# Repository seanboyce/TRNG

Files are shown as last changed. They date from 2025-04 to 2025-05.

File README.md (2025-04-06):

# Function

This circuit is designed to output random bytes out MQTT, each as a message. It works at 8-10k bytes per second depending on system voltage and the fact that the bitrate of the entropy source is variable by nature.

# What? Why? You could just use a seed phrase and standard cryptography

Yeah, that works fine and there's no real disadvantage.

I've been designing various quantum TRNGs for nearly 15 years as part of an elaborate practical joke. This is just the latest one. I won't tell you what the joke is. Perhaps I'll never tell anyone. 

The world could do with a little more whimsy and playful mystery right now, and this is just my little bit that I can share with you.

# How it works

The core entropy source is two transistors in an unusual configuration. This is an old technique analogous to the classic "zener diode" method. It has the advantage of producing a slower signal, easier to sample.
It outputs avalanche noise with heavy DC bias. There's some nice [summary here](http://www.reallyreallyrandom.com/zener/why-its-random/index.html).

We remove the DC component wth a capacitor, then use two hex inverters for amplification and pulse-shaping. The first hex inverter is running at ~12V and is configured as two inverting amplifiers -- this is really power inefficient and it gets a bit warm due to the digital part working in linear modes. A little heat sink is recommended. 

This unusual use of the hex inverter is to reduce the parts count and cost -- I have a lot of hex inverters lying around. If you needed better power efficiency (e.g. for battery-powered use), you could use an op-amp. OPA132 is pretty easy to use.

The next hex inverter operates more or less digitally, just shaping the signal into a clean square wave. This one does not get warm.

After that, an Attiny261A acts as a Von Neumann extractor to convert the square wave into usable, unbiased bits of entropy. 

The bytes are read by a Pi Pico W and pushed out MQTT. Basic authentication works. I didn't bother adding TLS.

It would be possible to just use the PIO of the Pi Pico instead of an Attiny261A. However, most of the time I don't actually want the Pi Pico or Wi-Fi, and am just using the entropy locally. If you wanted to do this, you would simply not populate the Attiny261A, and solder a wire between pin 9 of the Attiny socket, and whatever pin you want on the Pi Pico. That will bypass the Attiny261A and push the raw entropy signal directly to the Pi Pico. I would recommend writing your own Von Neumann extractor with the PIO.

# How to build it

## Notes on surface mount components

This design makes extensive use of surface-mount components. I have limited budget and time to spend on my hobbies, so I generally use the smallest possible SMT components to save both (standardize my parts library). If you find 0402 difficult to work with, then it's very fast to open up the KiCAD files in this repo, and replace all the 0402 resistors with 0603 in the schematic. Then just pull up the board design, update from the schematic, and touch up the routing -- you should be good to go, 0603 is pretty easy to hand-solder even without a hot air rework station and solder paste. A normal iron, coil of solder, and some patience will suffice.

If you want to redesign everything as through-hole, this will require a bit of a redesign. I would recommend purchasing a USB boost converter, not populating the integrated boost converter, and using the passthrough I've left you (J2). Then switch the CD4069 to the DIP version, and add in through-hole resistors and capacitors. I vaguely recall that the DIP version of the CD4069 has better thermal dissipation, you might be able to get away with a smaller heat sink or none at all -- I've gotten away without one in older designs (give it a careful test though).

## Building the current design

I recommend building the boost converter first, then give it some power and make sure the output voltage is sane. Should be between 12 and 13 volts. Note that the EN pin of the MT3608 should be connected to Vin -- else nothing will output at all. I just bridge the middle pin of J1 to Vin.

Once that's in, I put in the transistors (mind polarity!), the first hex inverter, and all the resistors and capacitors around them. Then I supply power again, for a short time, with a scope connected to the output of the first hex inverter. The scope is set to be AC coupled. I should see a pretty looking signal with a lot of noise. Then I cut power -- that first hex inverter can get sort of hot with no heat sink attached.

Then I get the buck converter / LM7803 in, as well as the final hex inverter. Then I test as above (scope can be AC or DC coupled), making sure the signal from the second hex inverter is a weird looking, but mostly clean square wave ranging from 0 to 3.3V.

If that's good, I flash the program (main.asm) to an Attiny261A (using AVR-ICE, STK500 or home-made programmer). For the first few boards, I put in a socket for the AVR, so I can pull it out and update the firmware. Then I quickly check again, specifically that the "new output" pin of the Attiny261A is pushing out 10 usec pusles, and that bits are coming out of the pins of PORTA.

At this point, I just load the program (main.py) into the Pi Pico, disconnect it from the USB cable, and plug it in. The onboard LED should light up if it's receiving power, and flicker slightly if it's pushing out MQTT. If it doesn't flicker, try turning it off and on again, sometimes it can fail to connect to Wi-Fi.

**DO NOT plug a USB cable into the Pi Pico while it is connected to this circuit** It is being powered by 3.3V. USB is 5V. Several components are likely to make sad electronic noises, fail violently, and lose their magic blue smoke.

As for what part goes where? It's all in the KiCAD schematic. I would recommend giving it a detailed look.

## The Von Neumann Extractor

This just measures two time intervals between 2 sets of 2 independent events (it could probably use 3 events instead of 4 to calculate 2 intervals, but whatever. It's much faster than fast enough now). If t1>t2, it records a 0. If t1<t2, it records a 1. If they are equal, it tries again.

I originally wrote this firmware *ages* ago. It was quite an experience to look at my ham-fisted assembly from 15 years ago. I redid it with many optimizations, which increased performance about 50x. Also it consumes less power. Use main.asm, not old_von_neumann.asm. Seriously, the latter is pretty awful.

I include both files, so that one day I may look back and consider *both attempts* primitive and silly. Got to keep that ego in check!

## Photo

Note the black "bodge wire" near the USB power input. This was necessary because of an error in the original design files. The version in this repository has been corrected, and you won't need to cut any traces / add weird wires and so on.

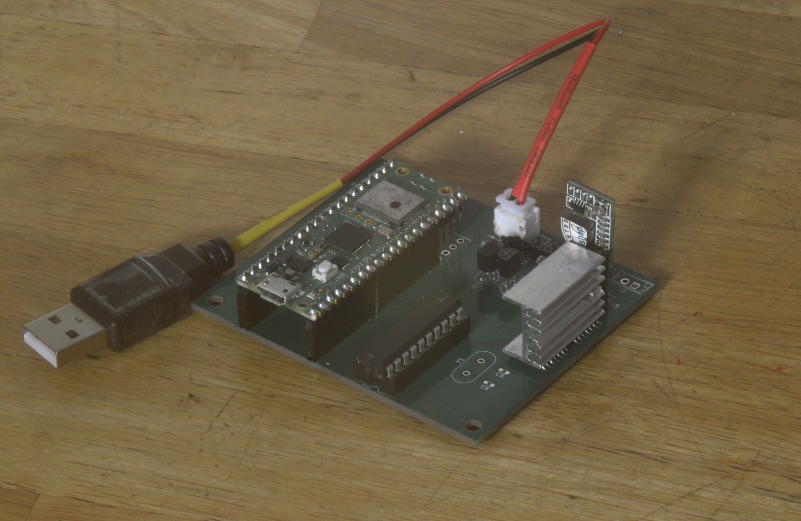
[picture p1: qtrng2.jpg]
photo of the trng


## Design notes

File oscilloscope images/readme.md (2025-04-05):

# Oscilloscope traces

These are here to help with any troubleshooting. There's some noise, mainly cause by he trying to hold 4 things in place at once rather than connect things to the board properly.

The first image is of the raw avalanche signal, AC coupled, just past C1. It has a strong DC bias before C1.

The second image is the cleaned signal coming out of the final hex inverter stage.

The final image is the 10usec pulse that come out of the attiny261A every time a new byte is ready.

If your signals don't look mostly like these, it's not working properly, even if you're getting output!

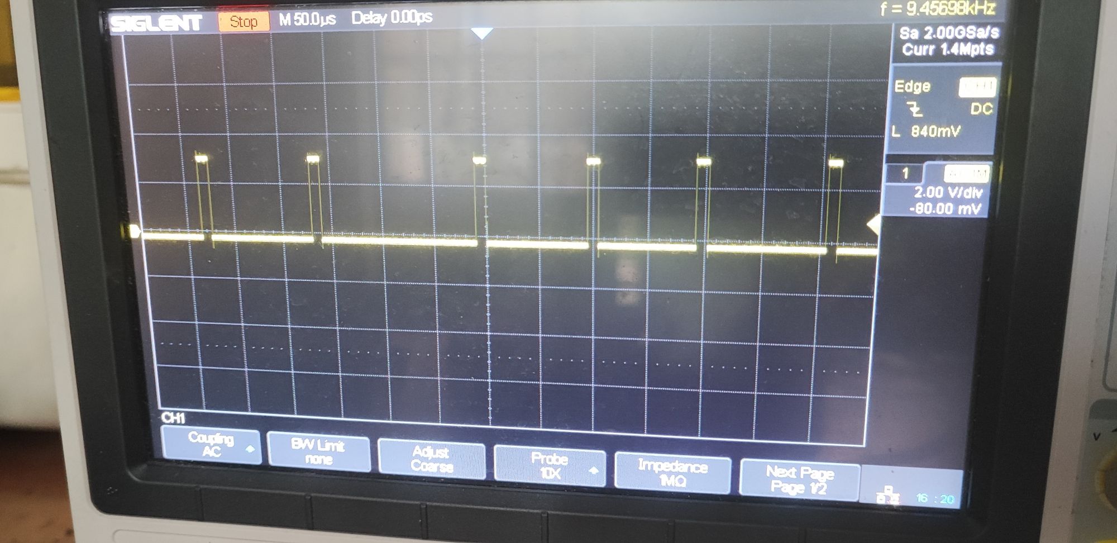
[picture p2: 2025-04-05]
oscilloscope images/3_new_data_pin.jpg

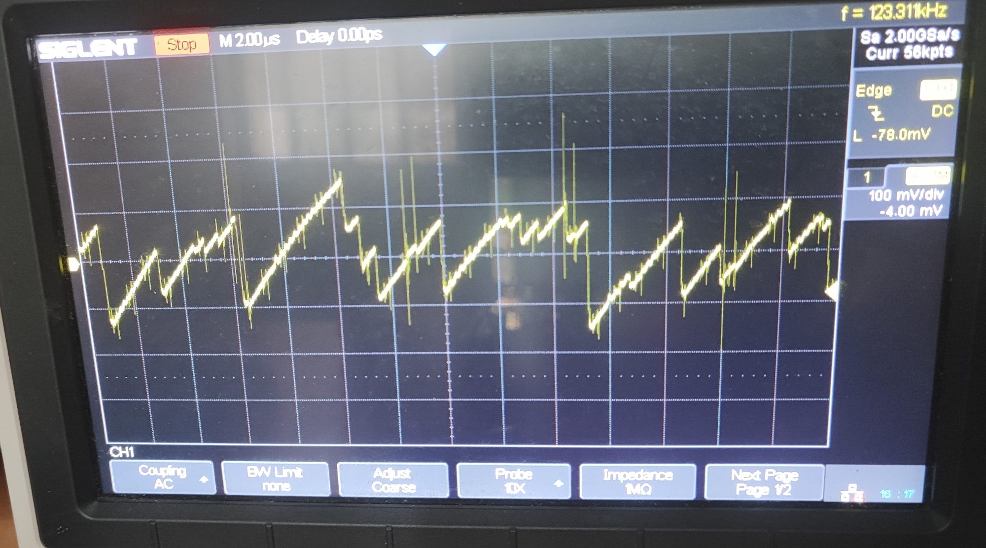
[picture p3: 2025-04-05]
oscilloscope images/1_transistor_output.jpg

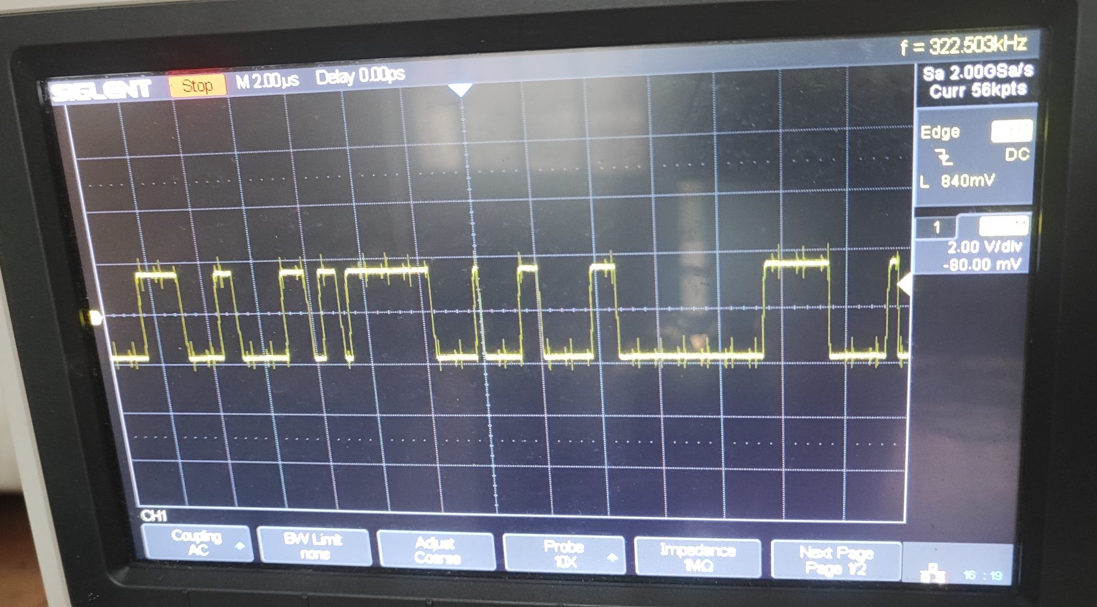
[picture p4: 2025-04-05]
oscilloscope images/2_final_hex_inverter_output.jpg

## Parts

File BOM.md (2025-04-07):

# Required:

## Resistors (all 0402):
- 1x 20k
- 1x 1k
- 3x 50k
- 1x 1M

## Capacitors and Inductors:
- 2x 22uF ceramic non-polar 1206
- 3x 0.1uF ceramic non-polar 0603
- 1x 22uH coil. Check size against KiCAD footprint.

## Discrete semiconductors:
- 1x SS24 Schottky diode SMT (unsure of package)
- 2x 2N5551 transistors TO-92

## ICs and modules:
- 2x CD4069UBM hex inverters
- 1x MT3608 boost converter IC
- 1x buck converter module -- the tiny cheap ones with just EN, Vin, GND, Vout
- 1x Attiny 261A
- 1x Pi Pico W

# Optional:
- 1x crystal
- 2x 12pF ceramic non-polar 0603
- 2x two-pin JST connector
- 1x LM7803 linear regulator (alternative to a buck converter to get 3.3V)
- ~~1x covenant with the Old Powers~~
- You'll probably want some female 2.5mm headers for the Pi Pico.

#Notes: 

1. The optional crystal as a clock source for the attiny is untested. Maybe double check I connected it right. If using it, the 12pF caps are required.
2. The JST connectors are handly for connecting power to the board through J1. It's expected that you bridge the middle pin of J1 to VCC of the input voltage. It's connected to the enable pin of the MT3608
3. J2 lets you bypass the integrated boost converter, e.g. if you just want to supply ~12V to the board. In this case, all of the boost converter parts should not be added to the board.
4. Strictly speaking, the Attiny261A could be eliminated by just using the PIO of the pi pico. However, I often use this design in cases where Internet connectivity is not useful -- in these cases I just don't populate the Pi Pico, which is more expensive than an Attiny261A.
5. Exact resistor values are not critical, however 1 + 0.6(R5/R6) gives you the output voltage of the boost converter. A ratio of 20 should get you between 12 and 13 volts.
6. Exact capacitor values are not critical either, except on the boost converter (those two 22uF)
7. Heck, the exact Schottky diode doesn't really matter much either. I just used the one I had
8. You can use other transistors, however 2N5551 starts avalanching at a relatively low voltage. Others may work. I selected the 2N5551 after trying a few types and measuring the avalanche signal frequency and the voltage it started at. It's probably not the best one, just the best one I have in stock.
9. Attiny261A is just the one I had lying around. I've also made this circuit with the attiny10 -- it just raises one of two outputs high when triggered, essentially providing one-shot, one bit output.

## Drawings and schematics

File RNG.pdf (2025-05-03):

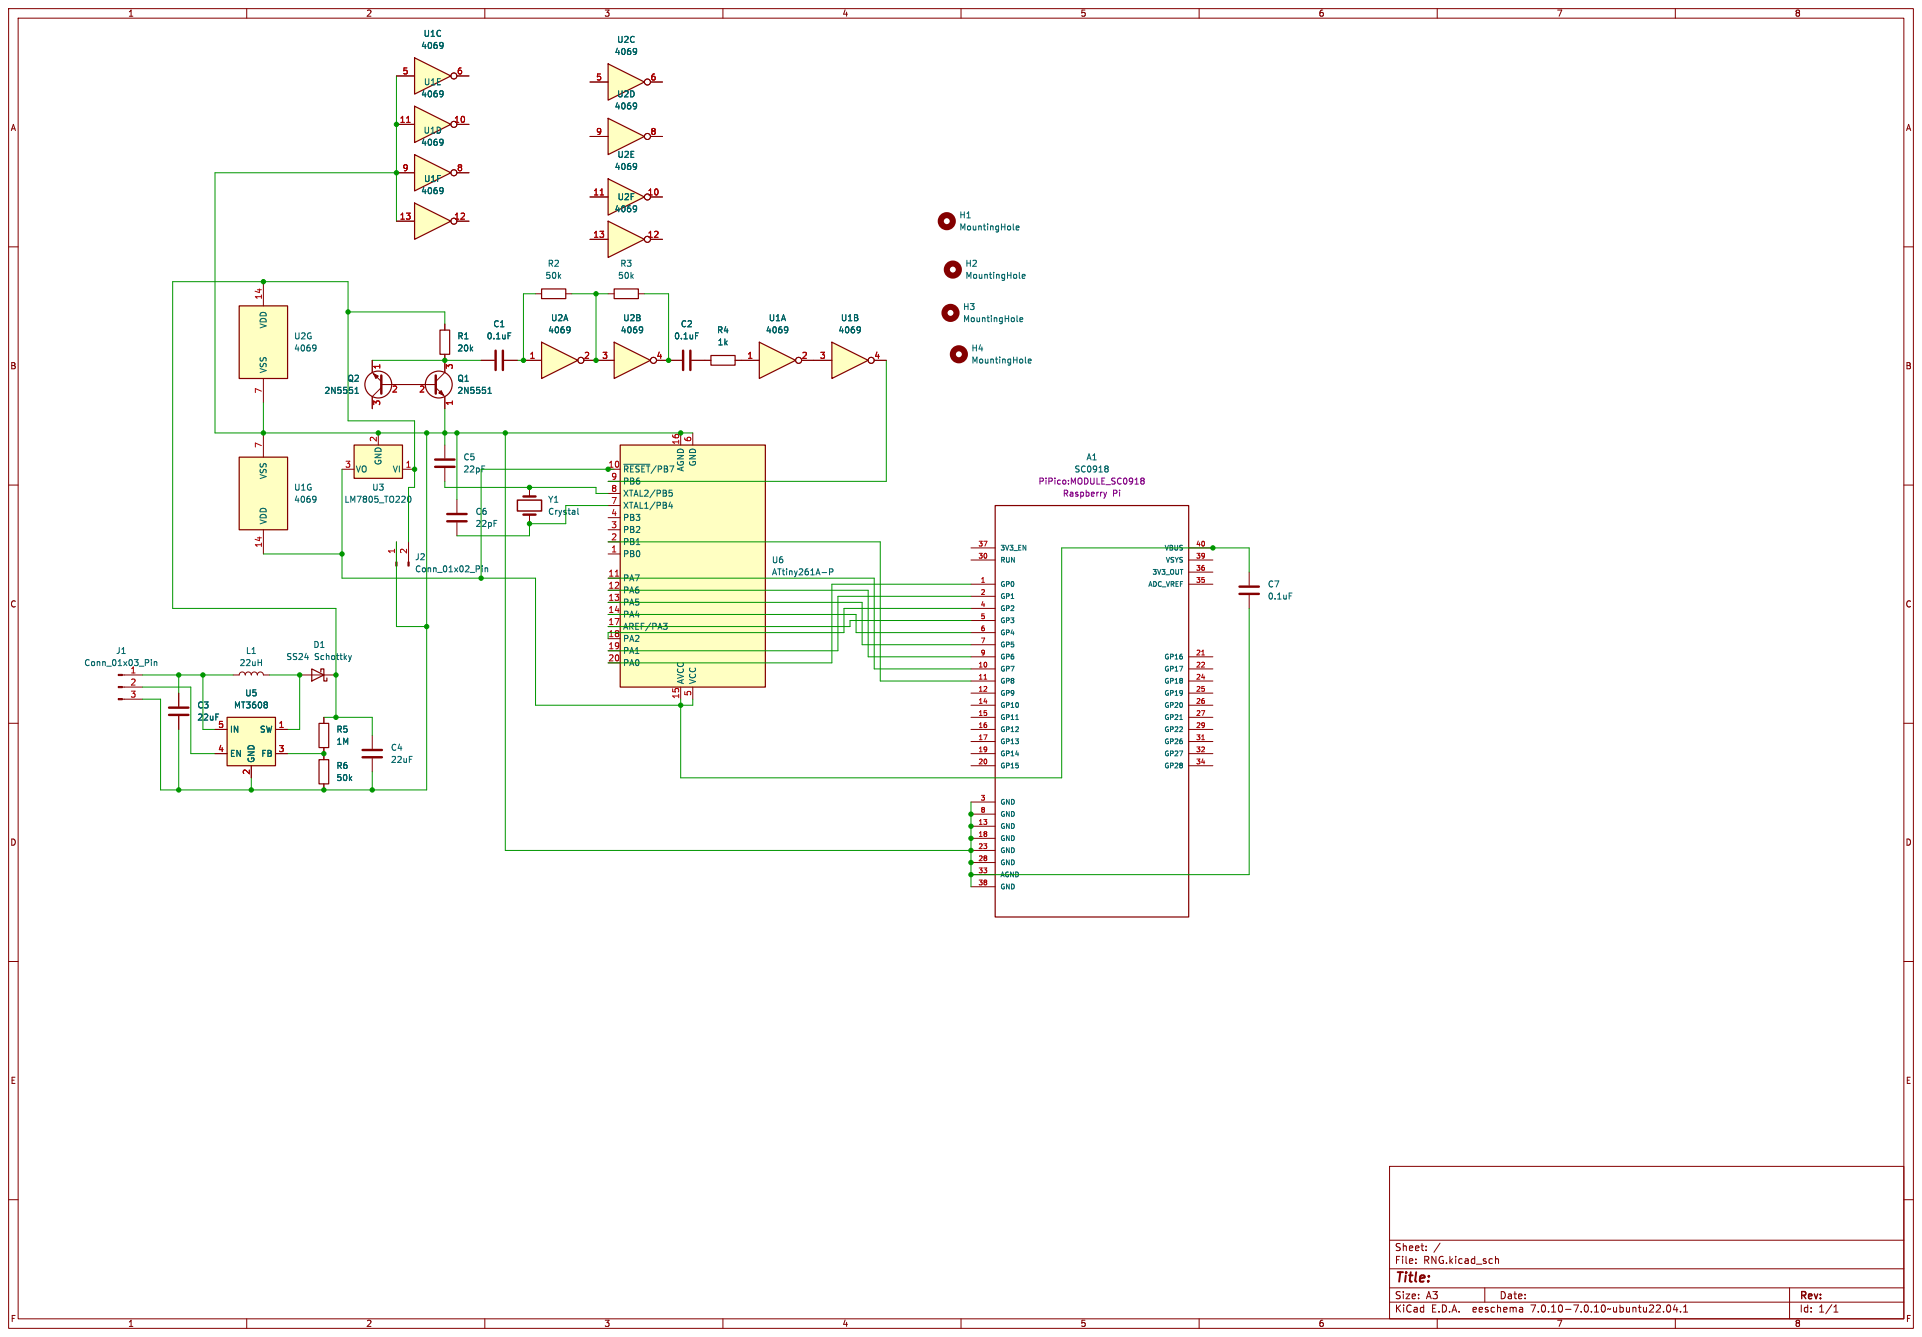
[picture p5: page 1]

H1 MountingHole H3 MountingHole H2 MountingHole H4 MountingHole

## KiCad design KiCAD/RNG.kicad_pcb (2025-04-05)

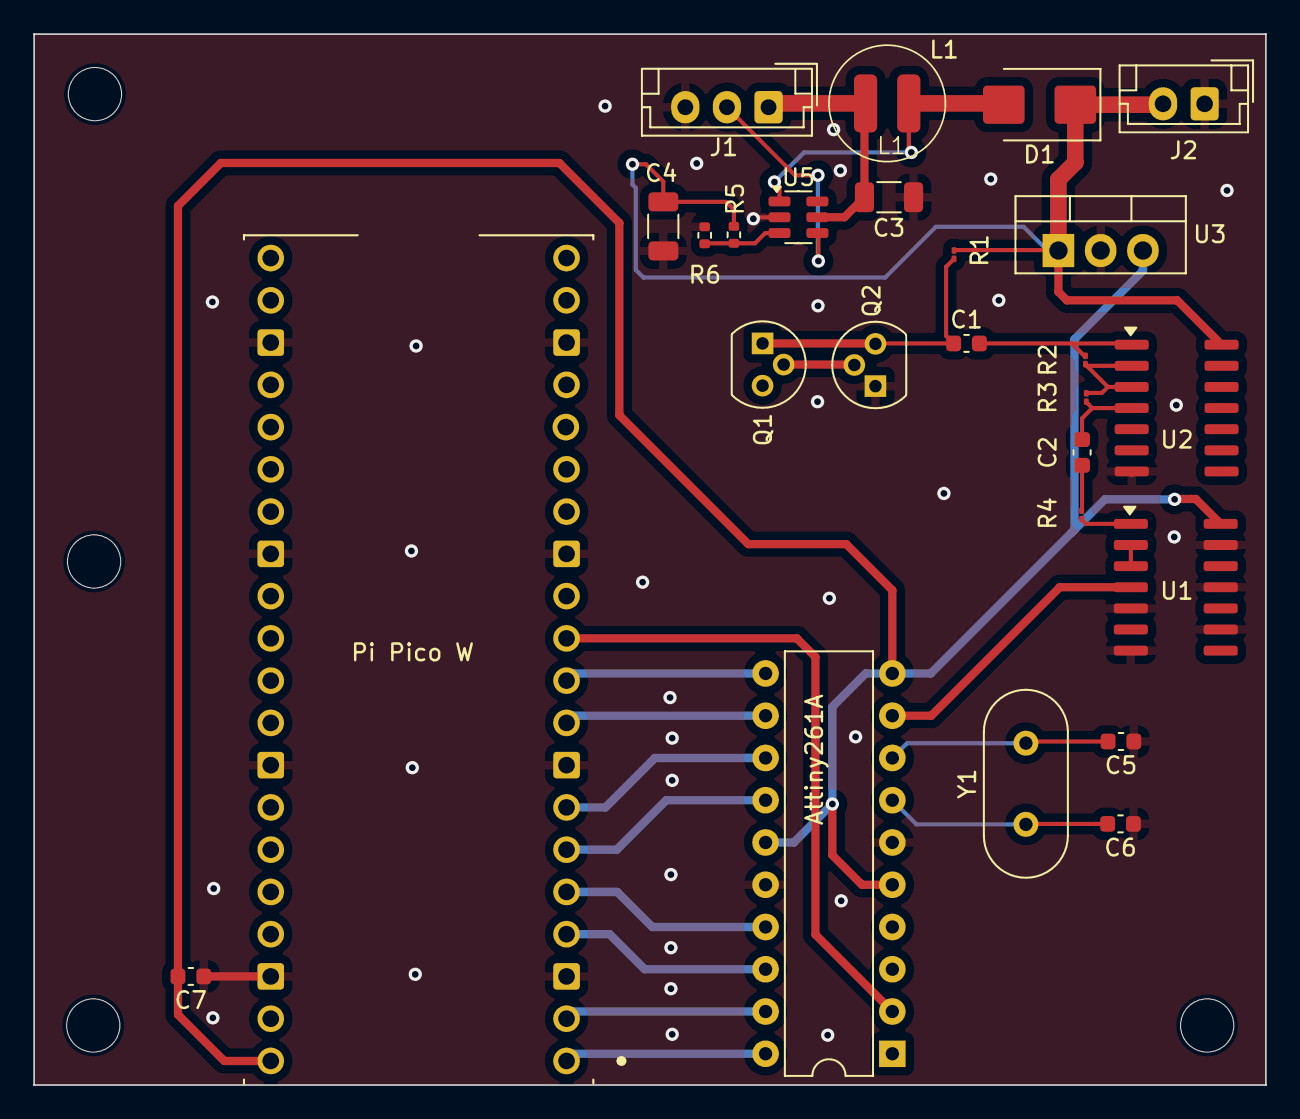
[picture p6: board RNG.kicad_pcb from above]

Board: 2 copper layers, 74.0 x 63.2 mm, 28 parts (0 on the bottom side), 24 nets.

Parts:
A1: SC0918; MODULE_SC0918
C1, C2, C7: 0.1uF; C_0603_1608Metric
C3, C4: C; C_1206_3216Metric
C5, C6: 22pF; C_0603_1608Metric
D1: D_Schottky; D_SMB
H1, H2, H3, H4: MountingHole; MountingHole_3.2mm_M3
J1: Conn_01x03_Pin; JST_EH_B3B-EH-A_1x03_P2.50mm_Vertical
J2: Conn_01x02_Pin; JST_EH_B2B-EH-A_1x02_P2.50mm_Vertical
L1: L; cd32
Q1, Q2: 2N5551; TO-92
R1: 20k; R_01005_0402Metric
R2, R3: 100k; R_01005_0402Metric
R4: 1k; R_01005_0402Metric
R5, R6: R; R_0402_1005Metric
U3: LM7805_TO220; TO-220-3_Vertical
U5: MT3608; SOT-23-6
U6: ATtiny261A-P; DIP-20_W7.62mm
Y1: Crystal; Crystal_HC49-U_Vertical

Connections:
unnamed: A1.3 (GND), A1.8 (GND), A1.13 (GND), A1.18 (GND), A1.23 (GND), A1.28 (GND), A1.33 (AGND), A1.38 (GND), C3.1, C4.2, C5.1, C6.1, C7.1, J1.3, J2.1, Q1.1 (E), R6.2, U3.2 (GND), U5.2 (GND), U6.6 (GND), U6.16 (AGND)
unnamed: A1.1 (GP0), U6.20 (PA0)
unnamed: A1.2 (GP1), U6.19 (PA1)
unnamed: A1.4 (GP2), U6.18 (PA2)
unnamed: A1.5 (GP3), U6.17 (AREF/PA3)
unnamed: A1.6 (GP4), U6.14 (PA4)
unnamed: A1.7 (GP5), U6.13 (PA5)
unnamed: A1.9 (GP6), U6.12 (PA6)
unnamed: A1.10 (GP7), U6.11 (PA7)
unnamed: A1.11 (GP8), U6.2 (PB1)
unnamed: A1.40 (VBUS), C7.2, U3.3 (VO), U6.5 (VCC), U6.10 (~RESET/PB7), U6.15 (AVCC)
unnamed: C1.2, R2.1
unnamed: C2.1, R3.2
unnamed: C2.2, R4.1
unnamed: D1.2 (A), L1.2, U5.1 (SW)
unnamed: C4.1, D1.1 (K), J2.2, R1.1, R5.1, U3.1 (VI)
unnamed: C3.2, J1.1, L1.1, U5.5 (IN)
unnamed: J1.2, U5.4 (EN)
unnamed: Q1.2 (B), Q2.2 (B)
unnamed: C1.1, Q1.3 (C), Q2.1 (E), R1.2
unnamed: R2.2, R3.1
unnamed: R5.2, R6.1, U5.3 (FB)
unnamed: C6.2, U6.7 (XTAL1/PB4), Y1.1
unnamed: C5.2, U6.8 (XTAL2/PB5), Y1.2

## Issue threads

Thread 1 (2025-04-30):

Add a PDF version of the design files

ospilos, 2025-04-30:
Mainly of the schematics. We are curious to see the exact circuit diagram, but not curious enough to install each and every EDA software besides the ones we use whenever we see a new interesting circuit.
Nevertheless, nice project and I hope for your crypto joke will stun and astound both your victim and audience.

seanboyce, 2025-05-03:
Sure, done! There's now a PDF of the schematic in the main directory for you.

As for the joke? I'm unlikely to ever reveal it. It's nice to have something secret to remember and laugh about sometimes :)

Oh, note that R1 should probably be more than 20k with the transistors in that configuration (as someone kindly pointed out). I stress tested for about a year and it was OK, but a higher value would be a bit less spicy. I'll get around to testing it and updating the schematics one of these weeks.

seanboyce, 2025-05-08:
Haha, no -- if those pranks exist, we don't mention them at all.

Closed 2025-05-03.

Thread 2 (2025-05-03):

R1 should probably be a higher resistance

seanboyce, 2025-05-03:
The transistors are being used in a very-not-recommended way (I *did* say the design was 'spicy'). Someone pointed out that the avalanche current will probably degrade them with time, and this could be somewhat mitigated by increasing the value of R1, probably to 100k or more. I'll test it before updating the schematics.

The current design was stress-tested for about a year, at which point I found no evidence of any problem. Still, I can't think of any good reason not to try and mitigate the issue -- it's not much work for me to just swap R1 with 100k or whatever and make sure the signal is still good. I'll find time to do so eventually, and then I'll close this issue.

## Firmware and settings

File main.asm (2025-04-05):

.include "tn261Adef.inc"
.CSEG
.ORG 0
rjmp RESET ; Reset Handler -- used for handling reset vector
rjmp event ; IRQ0 Handler -- used to detect falling edges for avalance events
rjmp RESET ; PCINT0 Handler -- not used
rjmp RESET ; Timer0 Capture Handler -- not used
rjmp RESET ; Timer0 Overflow Handler -- not used
rjmp RESET ; Timer0 Compare A Handler -- not used
rjmp RESET ; Timer0 Compare B Handler -- not used
rjmp RESET ; USI_OVF Handler -- not used
rjmp RESET ; EEPROM READY Handler -- not used
rjmp RESET ; Analog Comparator Handler -- not used
rjmp RESET ; ADC Conversion Complete Handler -- not used
rjmp RESET ; Watchdog Interrupt Handler -- not used
rjmp RESET ; INT1 -- not used
rjmp RESET ; TIMER0_COMPA -- not used
rjmp RESET ; TIMER0_COMPB -- not used
rjmp RESET ; TIMER0_CAPT -- not used
rjmp RESET ; TIMER1_COMPD -- not used
rjmp RESET ; FAULT_PROTECTION -- not used

RESET:
;BEGIN SETUP SECTION
CLR R16 ; cleanup
LDI r16, (1<<PRADC | 1<<PRTIM1 | 1<<PRUSI | 0<<PRTIM0); disable unused features to save power. We will use timer0.
OUT PRR, r16

ldi r16, (0<<CS02 | 0<<CS01) | (1<<CS00) ; set up timer, no prescaler
out TCCR0B, r16

ldi r16, (0<<ICEN0 | 0<<TCW0) | (0<<WGM00);Ensure normal 8-bit mode timer operation. Overflows are OK.
out TCCR0A, r16

;Set up ports. PortB, Pin 6 is input, pullup resistors disabled. The rest of A&B are used as potential outputs.
ldi r16,0b10111111 ; Set pin 6 as input, others as output
out DDRB,r16
ldi r16,0b00000000 ; make sure pullups are disabled, saves power. Also what's the point of reducing input noise when we're measuring noise?
out PORTB, r16
ldi r16,0b11111111 ; Port A as output
out DDRA,r16

LDI r16, (1<<ISC01 | 0<<ISC00 | 0<<SM0 | 0<<SM1 | 1<<SE); Interrupt on falling edge -- these are the avalanche events, we measure time between them. Set sleep mode IDLE and enable sleep.
;We could use deeper sleep, some state retention, and pin level interrupt instead of falling edge. This would save a little more power (irrelevant), at the cost of more complex code. We're not going to do that. 
OUT MCUCR, r16
LDI r16, (1<<INT0) ; actually enable INT0 (pin 9).
OUT GIMSK, r16
CLR R16 ; cleanup
CLR R21
; END SETUP SECTION


START:
; Set iteration number to 1
ldi r20, 0b00000001

CLR R21 ; clear out any stored entropy

;BEGIN SAMPLE 1 BIT
LOOP:
;WAIT for a first event to happen
SEI
SLEEP
;Now we start timing t1, the time between the first and second events.
out TCNT0L, r16 ; Clear timer
SEI ; enable global interrupt
SLEEP
MOV r17, r18 ; r17 is for the first bit
;Now we start timing t2, the time between the second and third events
out TCNT0L, r16 ; Clear timer
SEI ; enable global interrupt
SLEEP
NOP ; not really needed. Just for CPU cycle symmetry

cp r17, r18
breq LOOP ; if both timers equal, cancel this bit
cp r17, r18
brsh OUTPUT0 ; t1>t2, output 0
rjmp OUTPUT1 ; t1<t2, output 1

event:
IN r18,TCNT0L ; keep our interrupt routine tight
RET ;return but do not enable interrupts yet, we'll manage interrupts manually

OUTPUT0:
NOP ; Not needed. Just for symmetry.
cpi r20,0b10000000
brsh PAROUT
lsl r20 ; rotate iteration counter left -- just moves to the next bit.
RJMP LOOP

OUTPUT1:
add r21,r20
cpi r20,0b10000000
brsh PAROUT
lsl r20 ; rotate iteration counter left -- just moves to the next bit.
RJMP LOOP

PAROUT:
out PORTA,r21
out TCNT0L, r16 ; Clear timer
sbi PINB,1 ;toggle pin up
wait:
IN r18,TCNT0L ; just wait ~30usec. Not worth using sleep modes for this.
CPI r18, 0x50 ; wait 10usec
BRLT wait
sbi PINB,1 ;toggle pin down The reason we do this instead of just toggle once, is that the Pi Pico has no pin change interrupt. So on rising edge, it's always safe to read a value out of PORTA.
RJMP START

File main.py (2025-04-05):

from machine import Pin
import network
from time import sleep
from umqtt.simple import MQTTClient

# Setup LED, so we know it's on
led = machine.Pin("LED", machine.Pin.OUT)
led.toggle()

# Wi-Fi credentials
ssid = 'your_wifi_ssid'
password = 'your_wifi_password'

# A function to connect to Wi-Fi
def connect():
    #Connect to WLAN
    wlan = network.WLAN(network.STA_IF)
    wlan.active(True)
    wlan.connect(ssid, password)
    while wlan.isconnected() == False:
        print('Waiting for connection...')
        sleep(1)
    print(wlan.ifconfig())

# MQTT Server credentials
MQTT_SERVER = "your_mqtt_server"
MQTT_PORT = your_mqtt_port
MQTT_USER = "your_mqtt_username"
MQTT_PASSWORD = "your_mqtt_password"
MQTT_CLIENT_ID = ""
MQTT_KEEPALIVE = 7200
MQTT_SSL = False

#Initial states for data
data = 0
freshData = False

# A function to connect to MQTT
def connect_mqtt():
    try:
        client = MQTTClient(client_id=MQTT_CLIENT_ID,
                            server=MQTT_SERVER,
                            port=MQTT_PORT,
                            user=MQTT_USER,
                            password=MQTT_PASSWORD,
                            keepalive=MQTT_KEEPALIVE,
                            ssl=MQTT_SSL)
        client.connect()
        return client
    except Exception as e:
        print('Error connecting to MQTT:', e)
        raise  # Re-raise the exception to see the full traceback

# A function to publish to MQTT once connected
def publish_mqtt(topic, value):
    client.publish(topic, value)
    #print(topic)
    #print(value)
    #print("Publish Done")

# No Ports on raspberry pi, so we fake one with 8 pins
def readByte(newData):
    global data
    data = bit0.value() + 2*bit1.value() + 4* bit2.value() + 8*bit3.value() + 16*bit4.value() + 32*bit5.value() + 64*bit6.value() + 128*bit7.value()
    global freshData
    freshData = True


# Driver code on startup
connect()
client = connect_mqtt()

# Turn off LED once connected
led.toggle()


# Configure input pins
bit0 = Pin(0, Pin.IN, Pin.PULL_DOWN)
bit1 = Pin(1, Pin.IN, Pin.PULL_DOWN)
bit2 = Pin(2, Pin.IN, Pin.PULL_DOWN)
bit3 = Pin(3, Pin.IN, Pin.PULL_DOWN)
bit4 = Pin(4, Pin.IN, Pin.PULL_DOWN)
bit5 = Pin(5, Pin.IN, Pin.PULL_DOWN)
bit6 = Pin(6, Pin.IN, Pin.PULL_DOWN)
bit7 = Pin(7, Pin.IN, Pin.PULL_DOWN)
newData = Pin(8, mode=Pin.IN, pull=Pin.PULL_DOWN)
newData.irq(trigger=Pin.IRQ_RISING,handler=readByte)

print("Starting")

# Main loop. Basically fire off a byte out MQTT every time the interrupt triggers.

while True:
    if freshData:
        newData.irq(handler=None) # Don't interrupt sending data
        publish_mqtt("entropy", str(data))
        led.toggle() # LED will flicker if it's sending data
        newData.irq(trigger=Pin.IRQ_RISING,handler=readByte)
        freshData = False

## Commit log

2025-04-05 Create BOM
2025-04-05 Update README.md
    Add assembly guide
2025-04-05 Create main.py
    Add main micropython script for the Pi Pico
2025-04-05 Add files via upload
    Add scope trace images for reference
2025-04-06 Update README.md
    Oh right, I should explain that bodge wire
2025-04-07 Update BOM.md
    Forgot a coil in the BOM
2025-05-03 Add files via upload
    Add PDF of schematic so people without KiCAD installed can conveniently see it.
